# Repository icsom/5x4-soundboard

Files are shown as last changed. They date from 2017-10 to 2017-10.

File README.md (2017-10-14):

# 5x4-soundboard
DFPlayer Mini &amp; atmega328p based soundboard with 20 buttons

## SMT Prototype  

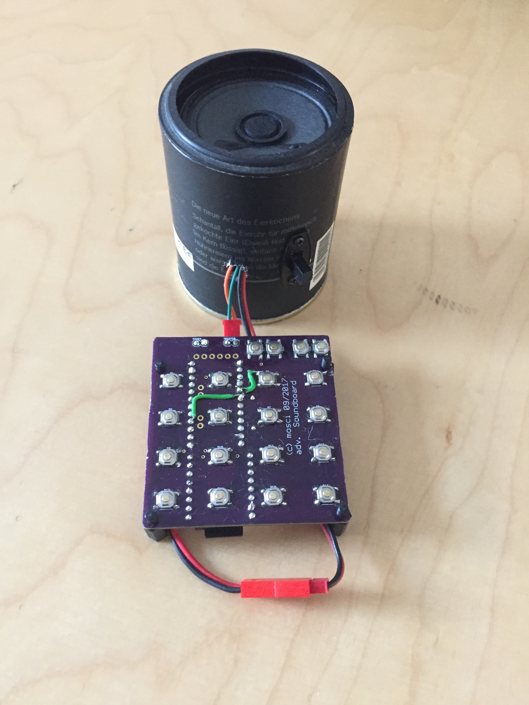
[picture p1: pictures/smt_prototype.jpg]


## 4x4 Prototype & 'Original'

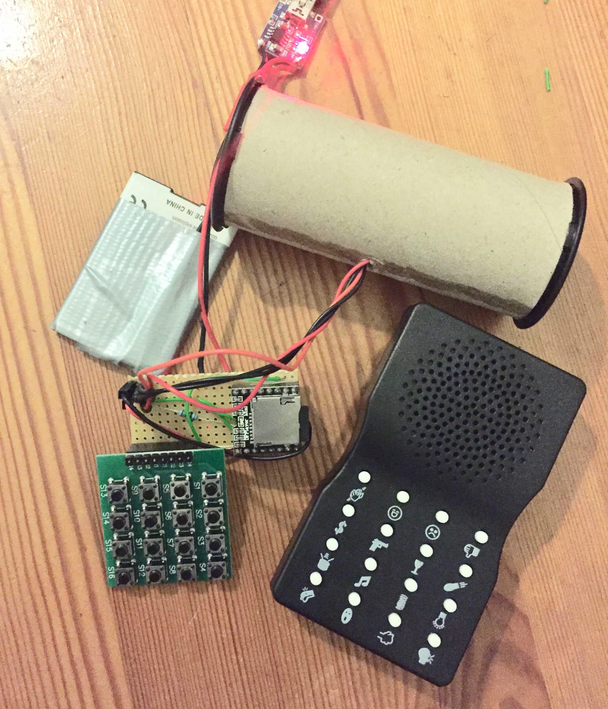
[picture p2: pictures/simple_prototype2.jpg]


## Breadboard

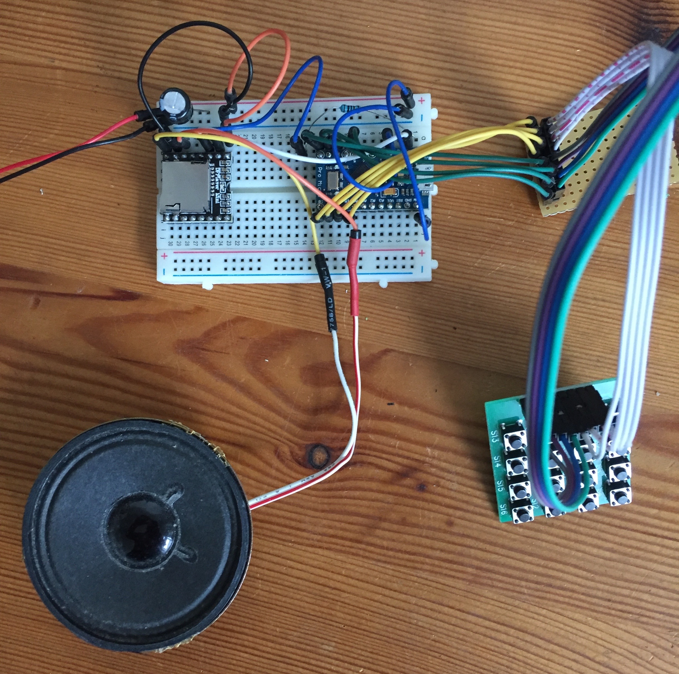
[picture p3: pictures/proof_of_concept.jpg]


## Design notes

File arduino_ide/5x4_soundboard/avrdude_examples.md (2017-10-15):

##avrdude command-line examples (programmer: mySmartUSB light)

###fuse-settings for 8MHz internal clock

avrdude -v -patmega328p -cstk500v2 -b115200 -P/dev/ttyUSB0 -e -Ulock:w:0x3F:m -Uefuse:w:0x05:m -Uhfuse:w:0xDA:m -Ulfuse:w:0xE2:m

###write 'arduino' bootloader for 8MHz internal clock (not needed for this project)

avrdude -v -patmega328p -cstk500v2 -b115200 -P/dev/ttyUSB0 -Uflash:w:ATmegaBOOT_168_atmega328_pro_8MHz.hex:i -Ulock:w:0x0F:m

###write intel-hex to flash

avrdude -v -patmega328p -cstk500v2 -b115200 -P/dev/ttyUSB0 -Uflash:w:5x4_soundboard.hex:i

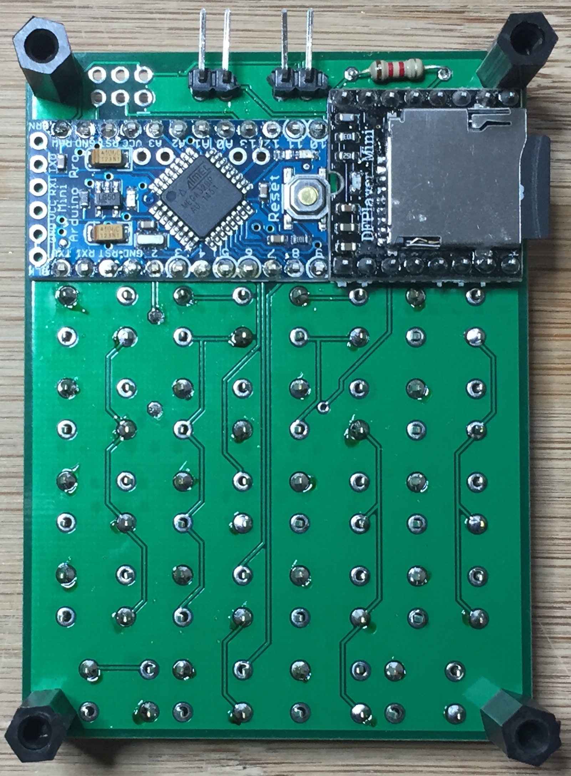
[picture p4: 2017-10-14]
pictures/arduino_pro_mini/pcb_populated_back.jpg

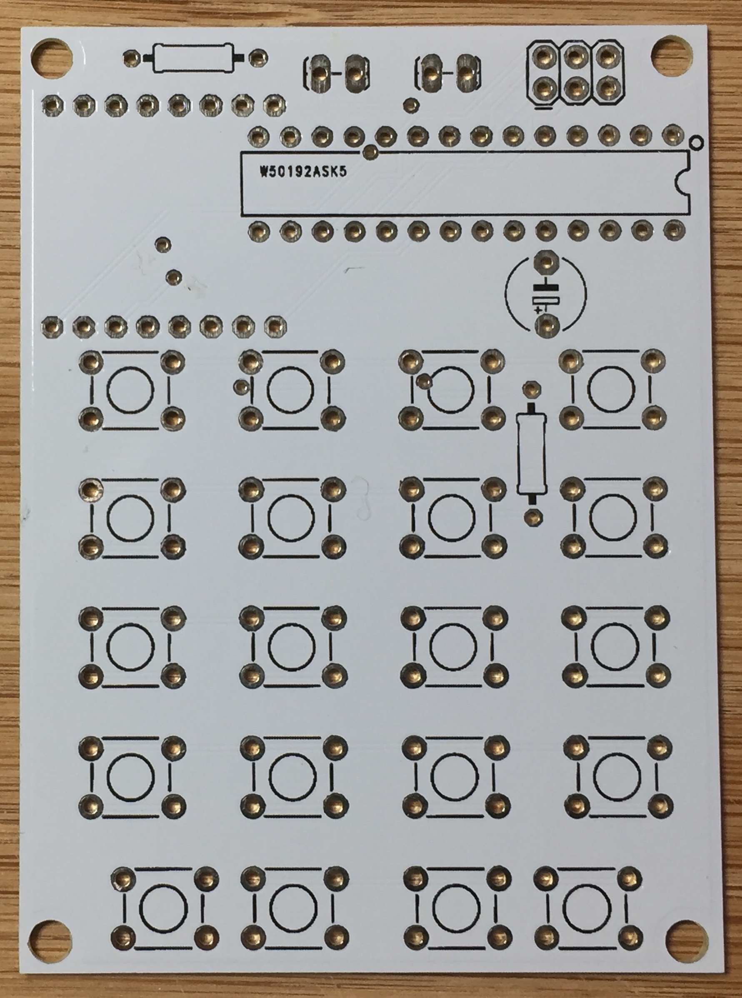
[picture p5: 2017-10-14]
pictures/atmega328p_dip/pcb.jpg

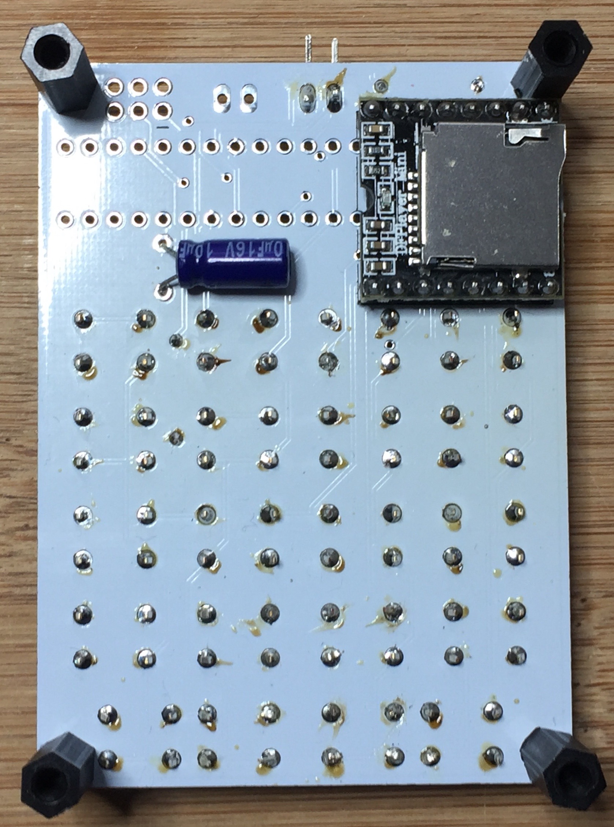
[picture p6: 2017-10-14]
pictures/atmega328p_tqfp/pcb_populated_back.jpg

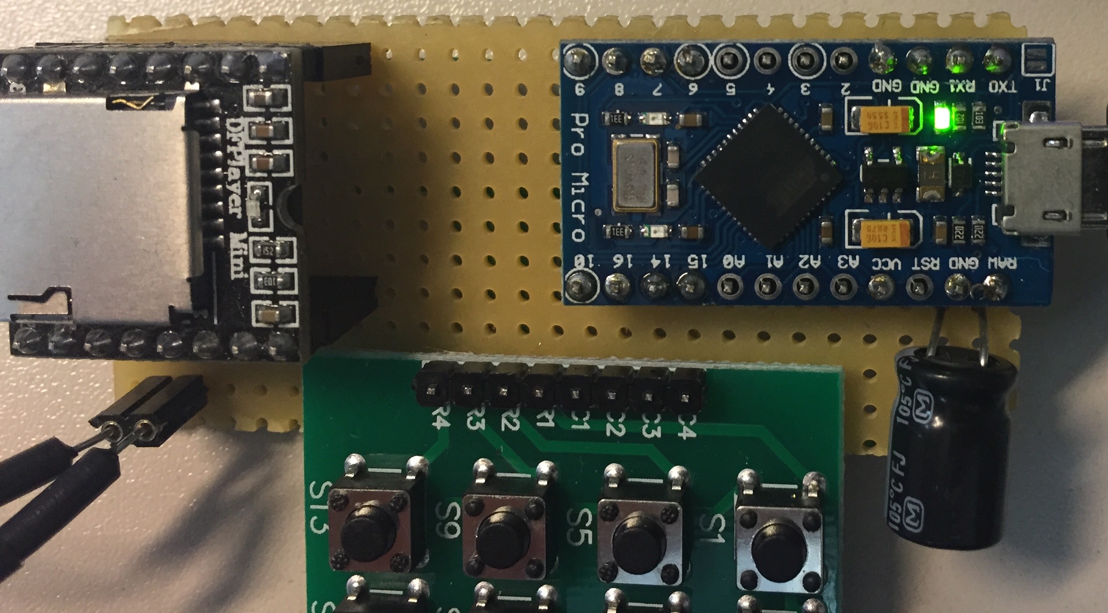
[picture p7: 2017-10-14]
pictures/simple_prototype.jpg

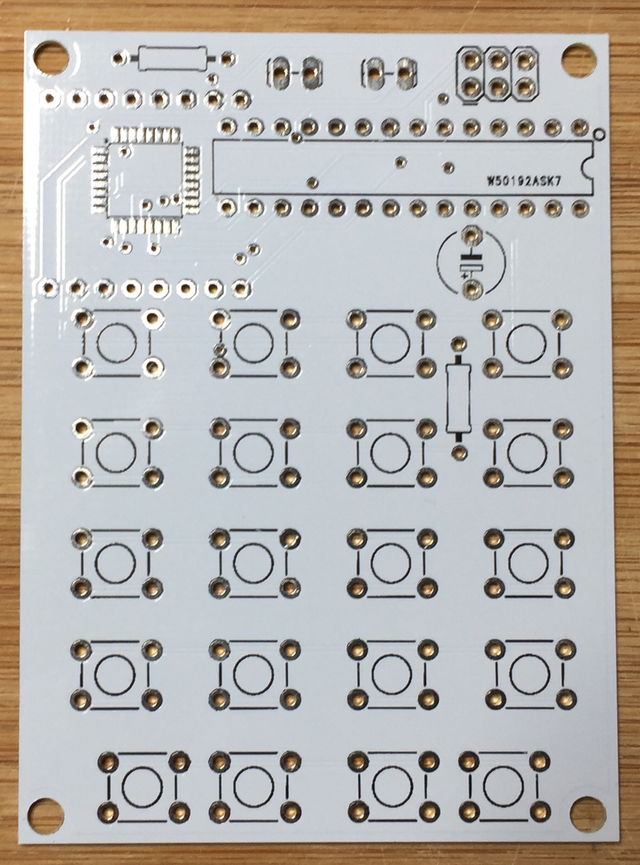
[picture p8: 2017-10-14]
pictures/atmega328p_tqfp/pcb.jpg

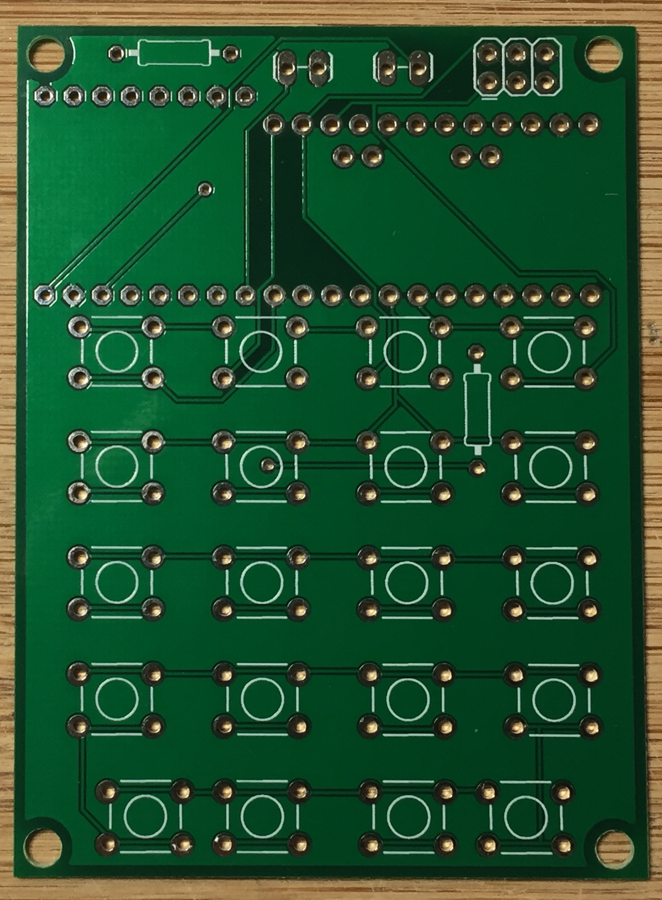
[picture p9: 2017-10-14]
pictures/arduino_pro_mini/pcb.jpg

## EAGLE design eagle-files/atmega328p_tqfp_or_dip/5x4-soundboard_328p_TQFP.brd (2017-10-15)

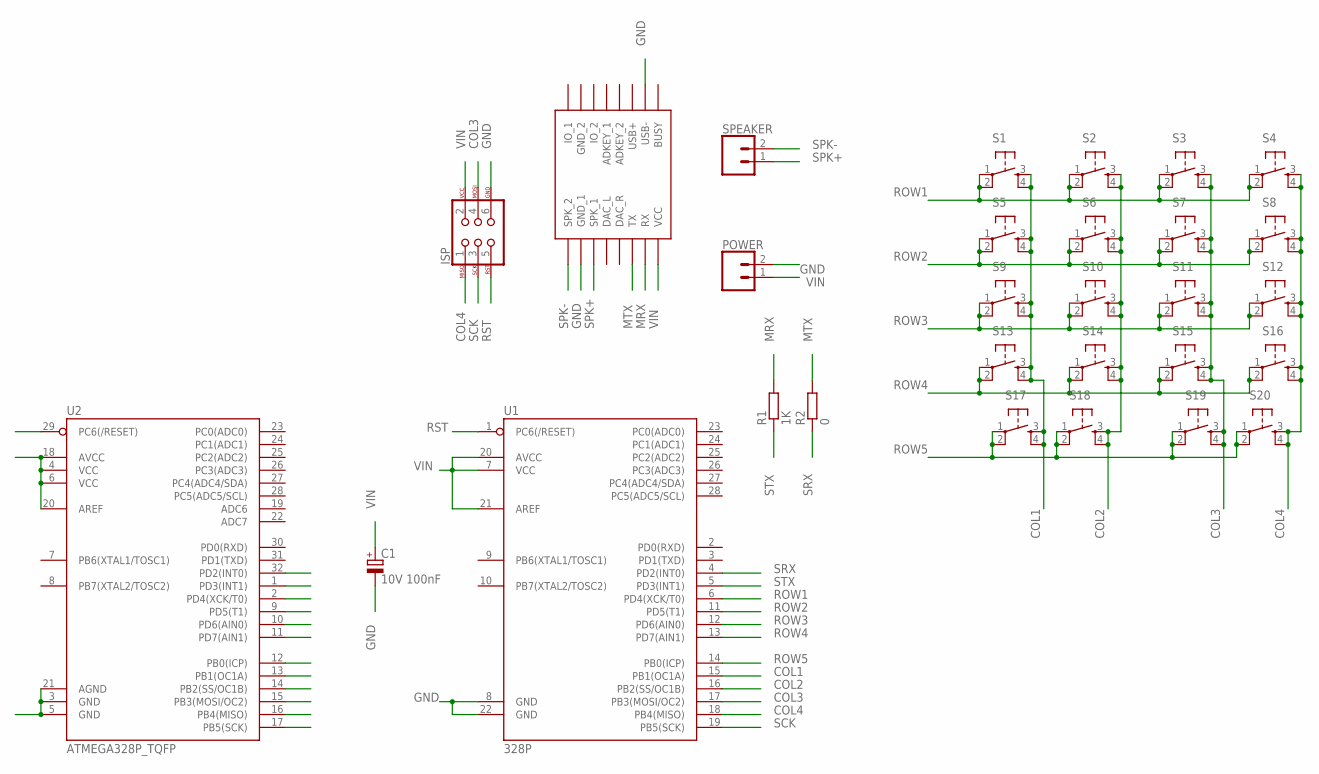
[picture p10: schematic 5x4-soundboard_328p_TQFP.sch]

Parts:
C1: 10V 100nF; E5-6
ISP: AVR_SPI_PROG_3X2PTH; 2X3
POWER: CONN_02LOCK_LONGPADS; 1X02_LOCK_LONGPADS
R1: 1K; 0207/10
R2: 0; 0207/10
S1, S2, S3, S4, S5, S6, S7, S8, S9, S10, S11, S12, S13, S14, S15, S16, S17, S18, S19, S20: TAC_SWITCHPTH; TACTILE-PTH
SPEAKER: CONN_02LOCK_LONGPADS; 1X02_LOCK_LONGPADS
U1: 328P; DIP28
U2: ATMEGA328P_TQFP; TQFP32-08
U$1: DFPLAYER

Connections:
COL1: S1.3, S1.4, S5.3, S5.4, S9.3, S9.4, S13.3, S13.4, S17.3, S17.4, U1.15 (PB1(OC1A)), U2.13 (PB1(OC1A))
COL2: S2.3, S2.4, S6.3, S6.4, S10.3, S10.4, S14.3, S14.4, S18.3, S18.4, U1.16 (PB2(SS/OC1B)), U2.14 (PB2(SS/OC1B))
COL3: ISP.4, S3.3, S3.4, S7.3, S7.4, S11.3, S11.4, S15.3, S15.4, S19.3, S19.4, U1.17 (PB3(MOSI/OC2)), U2.15 (PB3(MOSI/OC2))
COL4: ISP.1, S4.3, S4.4, S8.3, S8.4, S12.3, S12.4, S16.3, S16.4, S20.3, S20.4, U1.18 (PB4(MISO)), U2.16 (PB4(MISO))
GND: C1.-, ISP.6, POWER.2, U1.8 (GND), U1.22 (GND), U2.3 (GND), U2.5 (GND), U2.21 (AGND), U$1.GND_1, U$1.USB-
MRX: R1.2, U$1.RX
MTX: R2.2, U$1.TX
ROW1: S1.1, S1.2, S2.1, S2.2, S3.1, S3.2, S4.1, S4.2, U1.6 (PD4(XCK/T0)), U2.2 (PD4(XCK/T0))
ROW2: S5.1, S5.2, S6.1, S6.2, S7.1, S7.2, S8.1, S8.2, U1.11 (PD5(T1)), U2.9 (PD5(T1))
ROW3: S9.1, S9.2, S10.1, S10.2, S11.1, S11.2, S12.1, S12.2, U1.12 (PD6(AIN0)), U2.10 (PD6(AIN0))
ROW4: S13.1, S13.2, S14.1, S14.2, S15.1, S15.2, S16.1, S16.2, U1.13 (PD7(AIN1)), U2.11 (PD7(AIN1))
ROW5: S17.1, S17.2, S18.1, S18.2, S19.1, S19.2, S20.1, S20.2, U1.14 (PB0(ICP)), U2.12 (PB0(ICP))
RST: ISP.5, U1.1 (PC6(/RESET)), U2.29 (PC6(/RESET))
SCK: ISP.3, U1.19 (PB5(SCK)), U2.17 (PB5(SCK))
SPK+: SPEAKER.1, U$1.SPK1 (SPK_1)
SPK-: SPEAKER.2, U$1.SPK2 (SPK_2)
SRX: R2.1, U1.4 (PD2(INT0)), U2.32 (PD2(INT0))
STX: R1.1, U1.5 (PD3(INT1)), U2.1 (PD3(INT1))
VIN: C1.+, ISP.2, POWER.1, U1.7 (VCC), U1.20 (AVCC), U1.21 (AREF), U2.4 (VCC), U2.6 (VCC), U2.18 (AVCC), U2.20 (AREF), U$1.VCC

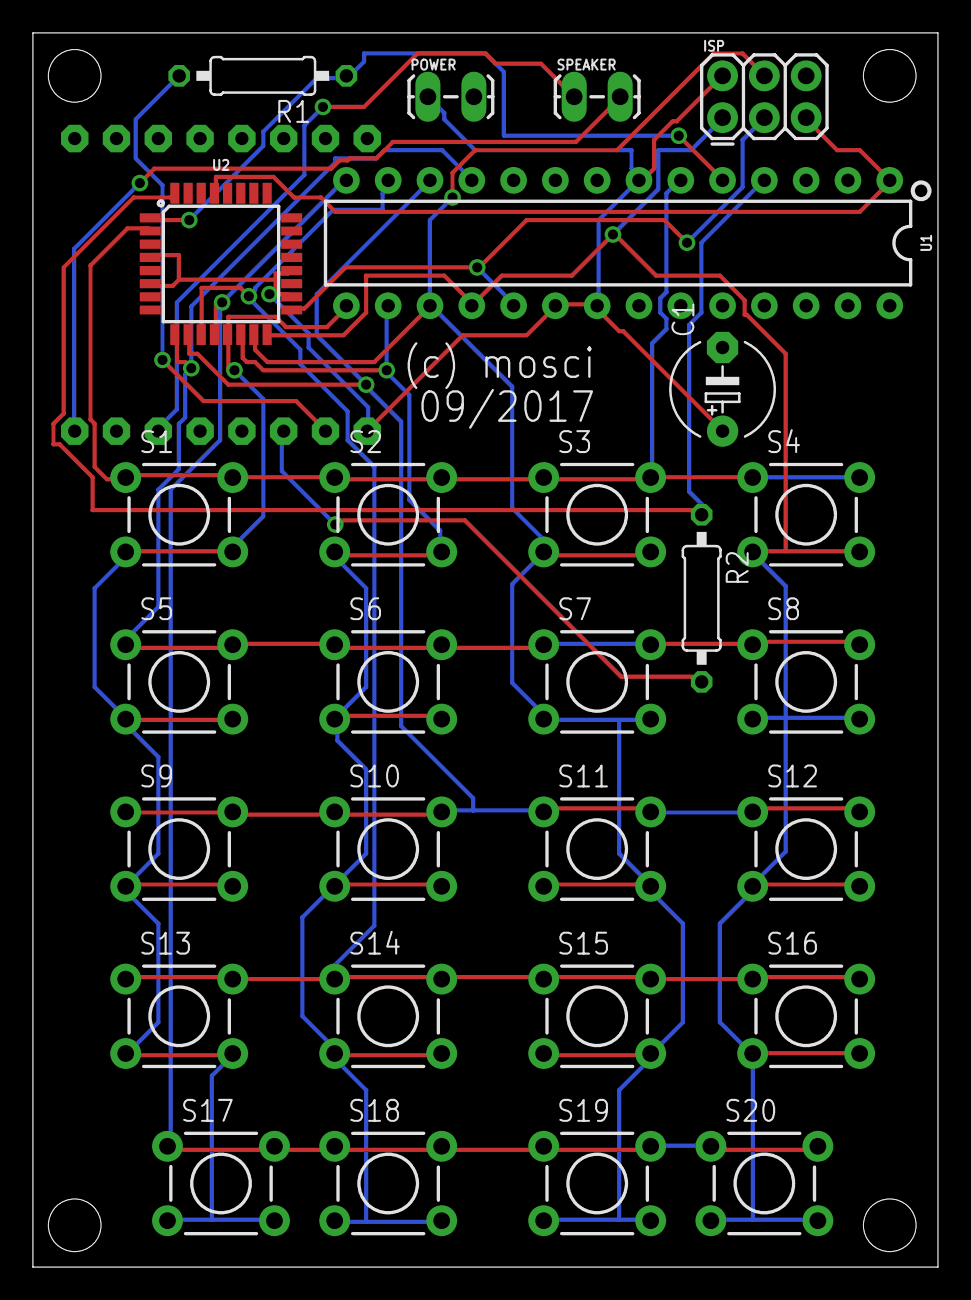
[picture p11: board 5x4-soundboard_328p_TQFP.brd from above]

Board: 2 copper layers, 55.0 x 75.0 mm, 29 parts (1 on the bottom side), 19 nets.

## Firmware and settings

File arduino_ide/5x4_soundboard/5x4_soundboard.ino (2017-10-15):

/*
  Keypad 
  5x4 tact-switch matrix
*/
#include <Keypad.h>

const byte ROWS = 5; //four rows
const byte COLS = 4; //four columns
char hexaKeys[ROWS][COLS] = {
  {'0','1','2','3'},
  {'4','5','6','7'},
  {'8','9','A','B'},
  {'C','D','E','F'},
  {'G','H','I','J'}
};
byte rowPins[ROWS] = {4, 5, 6, 7, 8}; //connect to the row pinouts of the keypad
byte colPins[COLS] = {9, 10, 11, 12}; //connect to the column pinouts of the keypad

//initialize an instance of class NewKeypad
Keypad customKeypad = Keypad( makeKeymap(hexaKeys), rowPins, colPins, ROWS, COLS); 


#include "Arduino.h"
#include "SoftwareSerial.h"
#include "DFRobotDFPlayerMini.h"

SoftwareSerial mySoftwareSerial(2, 3); // RX, TX for the communication with DFPlayer mini arduino TX <--- 1K Ohm rsisortor ---> RX DFPLayer
DFRobotDFPlayerMini myDFPlayer;
void printDetail(uint8_t type, int value);
unsigned long timer = millis();
int vol=30;



void setup() { 

  mySoftwareSerial.begin(9600);
  Serial.begin(9600);
  myDFPlayer.begin(mySoftwareSerial);
  myDFPlayer.setTimeOut(500); 
  myDFPlayer.EQ(DFPLAYER_EQ_NORMAL);
  myDFPlayer.outputDevice(DFPLAYER_DEVICE_SD);
  myDFPlayer.volume(vol);
}

void loop()
{
  char customKey = customKeypad.getKey();
   
  if (customKey){

    switch (customKey) {
        case '0':
            myDFPlayer.play(1);
          break;
        case '1':
            myDFPlayer.play(2);
          break;
        case '2':
            myDFPlayer.play(3);
          break;
        case '3':
            myDFPlayer.play(4);
          break;
        case '4':
            myDFPlayer.play(5);
          break;
        case '5':
            myDFPlayer.play(6);
          break;
        case '6':
            myDFPlayer.play(7);
          break;
        case '7':
            myDFPlayer.play(8);
          break;
        case '8':
            myDFPlayer.play(9);
          break;
        case '9':
            myDFPlayer.play(10);
          break;
        case 'A': 
            myDFPlayer.play(11);
          break;
        case 'B':
            myDFPlayer.play(12);
          break;
        case 'C':
            myDFPlayer.play(13);
          break;
        case 'D':
            myDFPlayer.play(14);
          break;
        case 'E':
            myDFPlayer.play(15);
          break;
        case 'F':
            myDFPlayer.play(16);
          break;
        case 'G':;
            myDFPlayer.previous();
          break;
        case 'H':
            myDFPlayer.next();
          break;
        case 'I':
            if(vol > 0) {vol--;}
          break;
        case 'J':
            if(vol < 30) {vol++;}
          break;
      }
      myDFPlayer.volume(vol);
  }
}

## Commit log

2017-10-14 added eagle-schematic as picture
2017-10-14 pictures of prototypes
2017-10-15 added compiled hex, arduino-ide-project and 8 MHz bootloader
2017-10-15 added eagle-files for atmega328p tqfp
    [5x4-soundboard_328p_TQFP.brd, 5x4-soundboard_328p_TQFP.sch]

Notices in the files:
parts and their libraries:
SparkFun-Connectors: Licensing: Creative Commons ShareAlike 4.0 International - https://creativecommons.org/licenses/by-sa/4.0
